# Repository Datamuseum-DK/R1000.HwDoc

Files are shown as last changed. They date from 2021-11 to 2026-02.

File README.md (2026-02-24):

This repository has moved
=========================

The future happens at: https://codeberg.org/Datamuseum-dk/R1000.DigitizingTheSchematics

Rational R1000/400 Machine Readable Hardware documentation
==========================================================

This repository contains the process and the result for
Datamuseum.dk's production of machine readable hardware
documentation for the Rational R1000/400 computer.

The desired output of this project was a machine readable net-list
based on the paper schematics, but because we think the process we
followed to get there may be of general interest, in the context
of computer hardware preservation, this repository captures
the process from A to Z.

But first a bit of…

HOWTO information
-----------------

To refresh/create KiCad symbol files:

	make RebuildSymbols

To add background images to schematics before editing (optional):

	make AddImages

To remove background images *AND* prepare .kicad_sch files for
commit after editing:

	make RemoveImages

If you want to play with the Image-processing:

	make ImageProc

Please note that a lot of disk-space is required for that, and
you may want to put that elsewhere with two symlinks:

	ln -s /tank/downloaded_stuff CacheDir
	ln -s /tank/working_directory WorkDir

Ok, and now to the explanation:

Why ?!
------

In Datamuseum.dk we have a
[running Rational R1000 Computer](https://datamuseum.dk/wiki/Rational/R1000s400)
and since that is in all likelyhood the only one in the world which
will ever run again, we want to implement a software emulation
to preserve this unique machine for posterity.

Normally one would simulate the instruction set of the computer, but
the R1000 has no instruction set, in the sense that the 16 bit codes
the Ada compiler's code generator produces is a private contract with
the Microcode which interprets them.

We have figured out quite a lot about these codes, for instance that
0x008c means:

	Action Heap_Access,Diana_Put_Node_On_Seq_Type 

So, yeah, that's not feasible to emulate.

Instead we aim to emulate at the microcode level, we have almost
complete hardware and some amount of microcode documentation, but
since even the microcode has subroutine calls, that is also a
tall order.

So our first stage is simulating the computer at the circuit
level, all the chips and all the connections between them, and
for that we need the schematics in a form which can be used
to build that simulation, a so-called "net-list".

This project is about producing that from bad-ish photocopies
of the original schematics.

The raw material
----------------

The raw material is 407 schematics on US-letter-sized photo-copies
in a 3-hole binder which we received with the computer, probably
copies of copies of copies of the original 23x14" VersaTec plots.

Here is a random snapshot from the TYPE board:

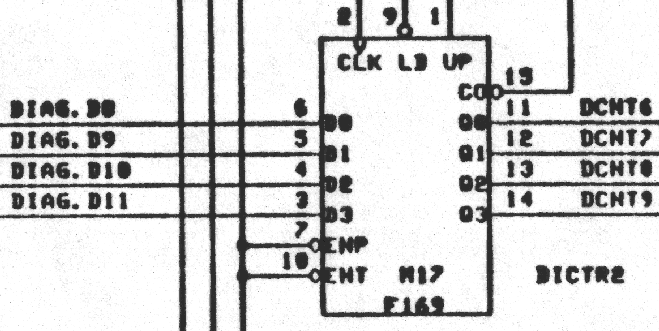
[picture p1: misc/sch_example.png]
Example schematic snippet


The linework is generally OK, but the glyphs have suffered greatly
through the copying, and there are a number of sets which as a rule
cannot be told apart graphically:  B+D, 0+8, E+F, H+M+N etc.

We have scanned the paper in 600DPI 8-bit gray and stored the
resulting images in loss-less PDFs in our
[BitStore](https://datamuseum.dk/wiki/Bits:Keyword/RATIONAL_1000/DOCS)
along with the rest of the documentation for the machine.

Machine reading schematics
--------------------------

The base plan was always to redraw the schematics by hand in KiCad,
but in the absense of prior art about machine reading schematics,
we decided to make an attempt at it, since even moderate succeess
looked like it could translate to substantial savings in time.

We got much better results than we even thought possible, where
more than 90% of all symbols on the schematic could be correctly
identified and placed.

This result comes from a universe of one, and undoubtedly overoptimized
to the these specific schematics, and deriving a lot of benefit from
the restrictions of the machine tools ("Daisy") used in their preparation.

In the end, we did not use the component-list output of the image
processing, we only used geometrically corrected projected images
as background images, since adding components and lines were as fast
of not faster as scrutinizing the machine-placed ones, and dwarfted
by the effort to enter all the textual information, where we never
managed to get a usable read-rate.

However, the code for component identification is included in this
repository, both for future reference, and because the rectangular
chips located add control-points to the geometric correction.

Geometric correction
--------------------

Being able to use the scanned schematics as background images in
KiCad is only realistic, if the skew and other distortions can
be reduced to a neglible level.

The drawing border very conveniently contains arrows for each
inch on the original plot size btween two rectangular frames.

These features, and others, can be machine recognized and used
to build four delaunay-triangulations:

	 from pixel(x, y) to inch(x)
	 from pixel(x, y) to inch(y)
	 from inch(x,y) to pixel(x)
	 from inch(x,y) to pixel(y)

Compared to traditional unskewing by rotation and similar
methods, a delaunay-triangulation permits adding as many
control-points as desired, making it possible to correct
not only skew, but also the uneven feed rates of the copying
machines used along the way:

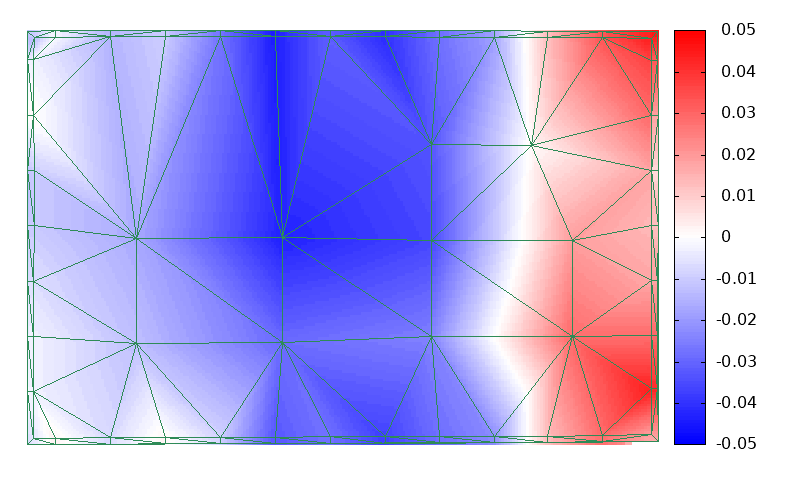
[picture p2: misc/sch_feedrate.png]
Example of uneven feed rate


This is a very typical pattern, for machines with two feed rollers,
one before and one after the imaging zone.  In this case the total
aberation is 0.1" which is a full grid point on the raw material.

The delaunay projections can be built in both  be built in both directions

Using the inch->pixel delaunay-projections to create a corrected
image is a very slow process, but gives very good results:

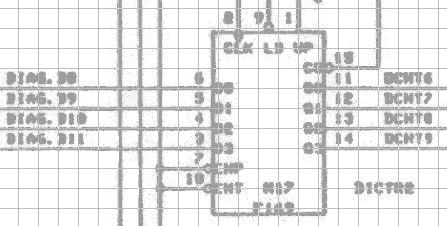
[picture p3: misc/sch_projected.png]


Schematic capture
-----------------

As mentioned above, we ended up doing the schematic capture by hand
using the scanned schematics as background:

Kicad schematic editor with background image

With a symbol library which as closely as possible matches
the original symbols, this is a really fast way to recapture
old schematics.

The most tedious part of the schematic capture was entering all
the text, because it took time to disambiguate 'B' and 'D' end so
on.

In order to catch as many mistakes as possible, we also typed
in the names and types of the chips found on the actual printed
circuit boards, and write scripts to cross-reference information
in the produced netlist with "ground truth".

Symbol library
--------------

Because the original schematics were prepared on Daisy and therefore
restricted to a 0.1" raster, probably in order to drive a VersaTec
electrostatic matrix plotter through a character generator, we were
able to create the KiCad symbols from "ascii-art" like this:

	   +-------+
	   |       |
	 11|       |
	-->+I0     |
	 12|       |
	-->+I1     |
	 13|       |
	-->+I2     |
	 14|       |
	-->+I3     |
	 15|       |10
	-->+I4  PEV+-->
	  1|       |
	-->+I5     |
	  2|       |9
	-->+I6  POD+-->
	  3|       |
	-->+I7     |
	  4|       |
	-->+I8     |
	  5|       |
	-->+I9     |
	  6|       |
	-->+I10    |
	  7|   xnn |
	-->+I11    |
	   |       |
	   | _     |
	   +-------+

These same ascii-arts is what enabled a very high recognition rate of
chips in the machine-reading experiment:  The pins on the four sides
of the chip, can be used to generate a "signature" of the pin locations
which can also be derived from the machine reading process:

	LI_I_I_I_I_I_I_I_I_I_I_IR________I___I__________TB

The non-rectangular components were entered by hand in KiCads component
editor, including the "deMorgan" variations many of them had:

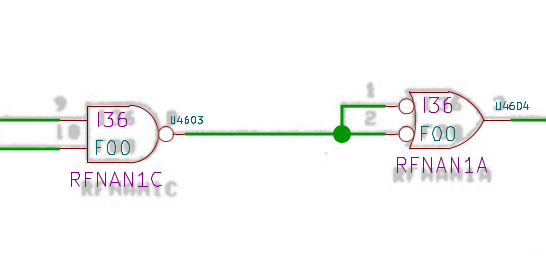
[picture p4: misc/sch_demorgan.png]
NAND gate with demorgan variant


Because the goal is to get a functional netlist for emulation
purposes, we did not bother with multiple units per symbol,
for instance the four NAND gates in a 74F00, we just have
a symbol called "F00" with a single NAND gate.

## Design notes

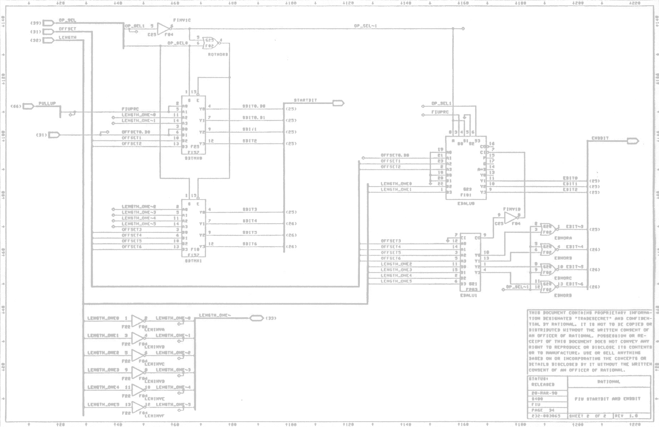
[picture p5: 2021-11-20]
BackgroundImages/FIU/0042/projected_75_light.png

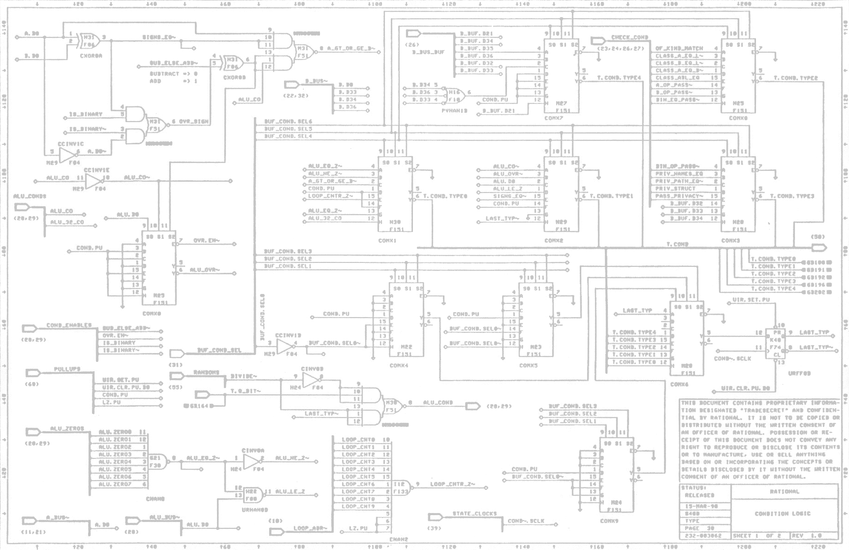
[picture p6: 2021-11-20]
BackgroundImages/TYP/0038/projected_75_light.png

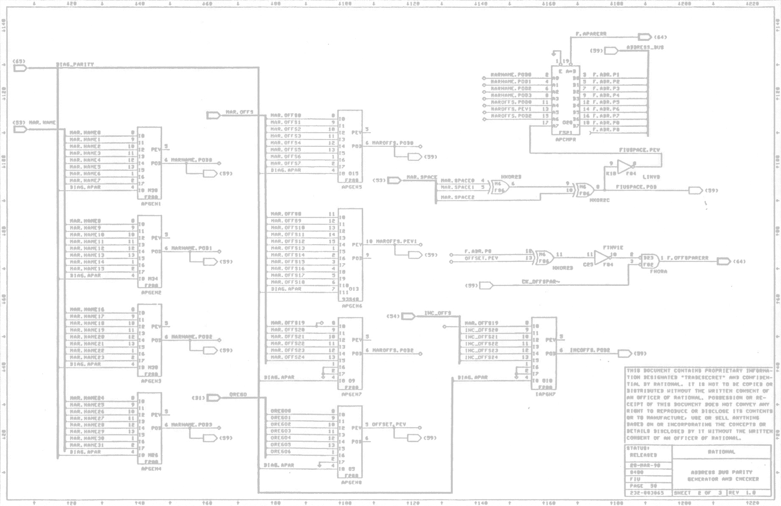
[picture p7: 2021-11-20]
BackgroundImages/FIU/0066/projected_75_light.png

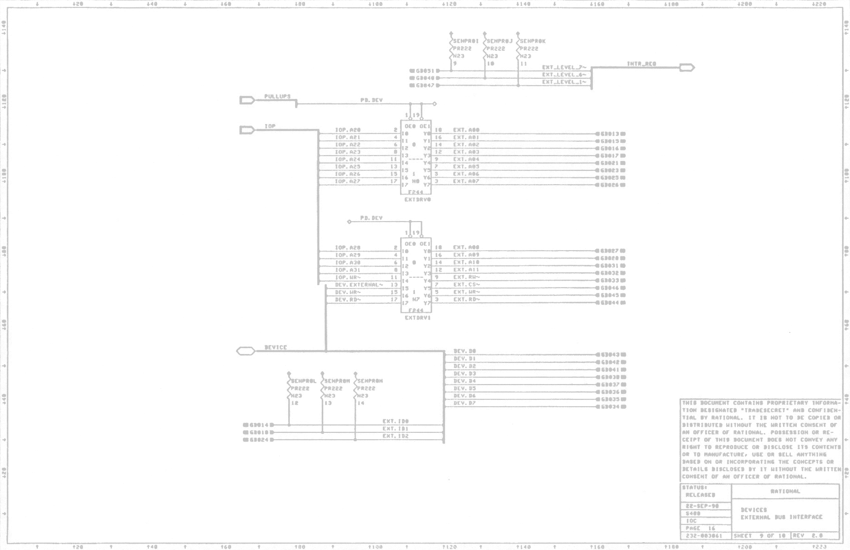
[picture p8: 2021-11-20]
BackgroundImages/IOC/0025/projected_75_light.png

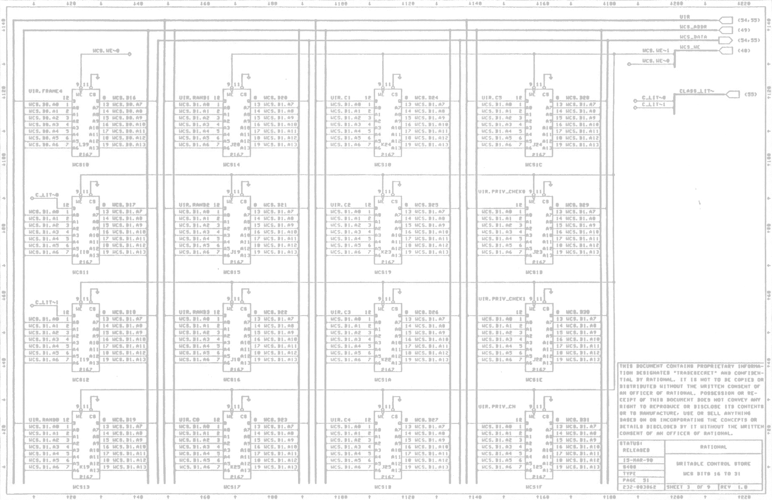
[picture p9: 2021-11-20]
BackgroundImages/TYP/0059/projected_75_light.png

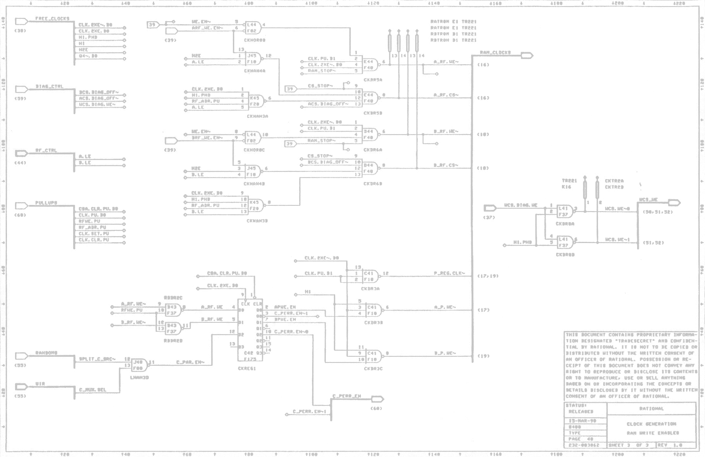
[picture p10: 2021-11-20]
BackgroundImages/TYP/0048/projected_75_light.png

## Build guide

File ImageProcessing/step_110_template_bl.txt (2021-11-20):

--------------------###############--------------------------------------------------##########--------                           -
--------------------###############--------------------------------------------------##########--------                           -
--------------------###############--------------------------------------------------##########--------                           -
--------------------###############--------------------------------------------------###########-------                           -
--------------------###############---------------------------------------------------##########-------                           -
--------------------###############---------------------------------------------------##########-------                           -
--------------------###############---------------------------------------------------##########-------                           -
--------------------###############---------------------------------------------------##########-------                           -
--------------------###############---------------------------------------------------##########-------                           -
--------------------###############---------------------------------------------------##########-------                           -
--------------------###############---------------------------------------------------##########-------                           -
--------------------###############---------------------------------------------------##########-------                           -
---------------------##############---------------------------------------------------#########--------                           -
---------------------##############---------------------------------------------------#########--------                           -
---------------------##############---------------------------------------------------#########--------                           -
---------------------##############---------------------------------------------------#########--------                           -
---------------------##############---------------------------------------------------#########--------                           -
---------------------##############---------------------------------------------------#########--------                           -
---------------------#############----------------------------------------------------#########--------                           -
---------------------##############---------------------------------------------------#########--------                           -
---------------------##############---------------------------------------------------#########--------                           -
---------------------##############--------------------------------------------------###########-------                           -
---------------------##############--------------------------------------------------###########-------                           -
---------------------##############--------------------------------------------------###########-------                           -
--------------------###############---------------------------------------------------##########-------                           -
--------------------###############---------------------------------------------------##########-------                           -
--------------------###############---------------------------------------------------##########-------                           -
--------------------###############---------------------------------------------------##########-------                           -
--------------------###############----------------------------------------------------#########-----------------------------------
--------------------###############---------------------------------------------------#########------------------------------------
--------------------###############---------------------------------------------------#########------------------------------------
--------------------###############----------------------------------------------------########------------------------------------
---------------------##############----------------------------------------------------#########-----------------------------------
---------------------##############----------------------------------------------------#########-----------------------------------
---------------------##############----------------------------------------------------#########-----------------------------------
---------------------##############----------------------------------------------------#########-----------------------------------
---------------------##############----------------------------------------------------##########----------------------------------
---------------------##############----------------------------------------------------#############--#----######------####------##
---------------------##############-----------------------------------------------------###########################################
--------------------###############-----------------------------------------------------###########################################
--------------------###############-----------------------------------------------------###########################################
--------------------###############-----------------------------------------------------###########################################
--------------------###############------------------------------------------------------##########################################
--------------------###############-------------------------------------------------------#########################################
--------------------###############--------------------------------------------------------#####--##----------###----------------##
--------------------###############------------------------------------------------------------------------------------------------
---------------------##############------------------------------------------------------------------------------------------------
---------------------##############------------------------------------------------------------------------------------------------
--------------------###############------------------------------------------------------------------------------------------------
--------------------################-----------------------------------------------------------------------------------------------
--------------------################-----------------------------------------------------------------------------------------------
--------------------################-----------------------------------------------------------------------------------------------
--------------------################-----------------------------------------------------------------------------------------------
--------------------################-----------------------------------------------------------------------------------------------
---------------------##############------------------------------------------------------------------------------------------------
---------------------##############------------------------------------------------------------------------------------------------
---------------------###############-----------------------------------------------------------------------------------------------
---------------------##############------------------------------------------------------------------------------------------------
---------------------##############------------------------------------------------------------------------------------------------
---------------------##############------------------------------------------------------------------------------------------------
---------------------##############------------------------------------------------------------------------------------------------
---------------------##############------------------------------------------------------------------------------------------------
---------------------##############------------------------------------------------------------------------------------------------
---------------------##############------------------------------------------------------------------------------------------------
----------------------#############------------------------------------------------------------------------------------------------
---------------------##############------------------------------------------------------------------------------------------------
---------------------###############-----------------------------------------------------------------------------------------------
---------------------##############------------------------------------------------------------------------------------------------
---------------------##############------------------------------------------------------------------------------------------------
---------------------###############-----------------------------------------------------------------------------------------------
---------------------###############-----------------------------------------------------------------------------------------------
----------------------##############-----------------------------------------------------------------------------------------------
----------------------##############-----------------------------------------------------------------------------------------------
----------------------##############-----------------------------------------------------------------------------------------------
----------------------##############-----------------------------------------------------------------------------------------------
----------------------##############-----------------------------------------------------------------------------------------------
----------------------#############------------------------------------------------------------------------------------------------
---------------------##############------------------------------------------------------------------------------------------------
---------------------##############------------------------------------------------------------------------------------------------
----------------------##############-----------------------------------------------------------------------------------------------
----------------------##############-----------------------------------------------------------------------------------------------
----------------------##############-----------------------------------------------------------------------------------------------
----------------------##############-----------------------------------------------------------------------------------------------
----------------------##############-----------------------------------------------------------------------------------------------
----------------------##############-----------------------------------------------------------------------------------------------
----------------------##############-----------------------------------------------------------------------------------------------
----------------------##############-----------------------------------------------------------------------------------------------
----------------------##############-----------------------------------------------------------------------------------------------
----------------------##############-----------------------------------------------------------------------------------------------
----------------------##############-----------------------------------------------------------------------------------------------
----------------------##############-----------------------------------------------------------------------------------------------
----------------------##############-----------------------------------------------------------------------------------------------
----------------------##############-----------------------------------------------------------------------------------------------
----------------------##############-----------------------------------------------------------------------------------------------
----------------------###############----------------------------------------------------------------------------------------------
----------------------###############----------------------------------------------------------------------------------------------
----------------------#################--------------###-------#--##--#-----#---#--##-----------------------##---------------------
----------------------####################-###-####################################################################################
----------------------#############################################################################################################
----------------------#############################################################################################################
----------------------#############################################################################################################
----------------------#############################################################################################################
----------------------#############################################################################################################
-----------------------############################################################################################################
-----------------------############################################################################################################
-----------------------############################################################################################################
-----------------------############################################################################################################
------------------------###########################################################################################################
-------------------------################-######################################-##################################################
------------------------#--------------------------------##############--------------------------------###-------#-----------------
-----------------------------------------------------------------------------------------------------------------------------------
-----------------------------------------------------------------------------------------------------------------------------------
-----------------------------------------------------------------------------------------------------------------------------------
-----------------------------------------------------------------------------------------------------------------------------------
-----------------------------------------------------------------------------------------------------------------------------------
-----------------------------------------------------------------------------------------------------------------------------------
-----------------------------------------------------------------------------------------------------------------------------------
-----------------------------------------------------------------------------------------------------------------------------------
-----------------------------------------------------------------------------------------------------------------------------------
-----------------------------------------------------------------------------------------------------------------------------------
-----------------------------------------------------------------------------------------------------------------------------------
-----------------------------------------------------------------------------------------------------------------------------------
-----------------------------------------------------------------------------------------------------------------------------------
-----------------------------------------------------------------------------------------------------------------------------------
-----------------------------------------------------------------------------------------------------------------------------------
-----------------------------------------------------------------------------------------------------------------------------------
-----------------------------------------------------------------------------------------------------------------------------------
-----------------------------------------------------------------------------------------------------------------------------------

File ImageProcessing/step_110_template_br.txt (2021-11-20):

-------------------###########----------------##########-----------------
--------------------##########----------------##########-----------------
--------------------##########----------------##########-----------------
--------------------##########----------------##########-----------------
--------------------##########----------------##########-----------------
--------------------##########----------------##########-----------------
--------------------##########----------------##########-----------------
--------------------##########----------------##########-----------------
--------------------##########-----------------#########-----------------
---------------------#########-----------------#########-----------------
---------------------#########-----------------########------------------
--------------------##########-----------------#########-----------------
--------------------##########-----------------#########-----------------
-------------------###########-----------------#########-----------------
-#----------###--#############-----------------#########-----------------
####-#########################-----------------#########-----------------
##############################-----------------#########-----------------
##############################-----------------#########-----------------
##############################-----------------#########-----------------
##############################-----------------#########-----------------
##############################-----------------#########-----------------
------------------############-----------------#########-----------------
--------------------##########-----------------#########-----------------
---------------------#########-----------------#########-----------------
---------------------#########-----------------##########----------------
---------------------#########-----------------##########----------------
---------------------#########-----------------#########-----------------
---------------------#########-----------------#########-----------------
---------------------#########-----------------#########-----------------
---------------------#########-----------------#########-----------------
---------------------#########-----------------#########-----------------
---------------------#########-----------------#########-----------------
---------------------#########-----------------#########-----------------
---------------------#########-----------------#########-----------------
---------------------#########-----------------#########-----------------
---------------------#########-----------------#########-----------------
---------------------#########-----------------#########-----------------
---------------------#########-----------------#########-----------------
---------------------#########-----------------#########-----------------
--------------------##########-----------------#########-----------------
---------------------#########-----------------#########-----------------
---------------------#########-----------------##########----------------
---------------------#########-----------------#########-----------------
---------------------#########-----------------#########-----------------
---------------------##########----------------#########-----------------
---------------------##########----------------#########-----------------
---------------------##########----------------#########-----------------
---------------------##########----------------#########-----------------
---------------------#########-----------------#########-----------------
---------------------#########-----------------#########-----------------
---------------------#########-----------------##########----------------
---------------------#########-----------------#########-----------------
---------------------#########------------------########-----------------
---------------------#########------------------########-----------------
---------------------#########------------------########-----------------
---------------------#########------------------########-----------------
---------------------#########-----------------#########-----------------
----------------------########-----------------##########----------------
---------------------#########-----------------##########----------------
---------------------#########-----------------##########----------------
---------------------#########-----------------##########----------------
---------------------#########-----------------##########----------------
---------------------#########-----------------##########----------------
----------------------########-----------------##########----------------
----------------------########-----------------##########----------------
---------------------#########-----------------##########----------------
---------------------#########------------------#########----------------
--------------------##########------------------########-----------------
-----#--------################------------------########-----------------
#############################-------------------#########----------------
#############################-------------------########-----------------
#############################-------------------########-----------------
#############################------------------#########-----------------
############################--------------------########-----------------
#######---------------#####---------------------########-----------------
------------------------##----------------------########-----------------
------------------------------------------------########-----------------
------------------------------------------------########-----------------
-----------------------------------------------##########----------------
-----------------------------------------------##########----------------
-----------------------------------------------#########-----------------
------------------------------------------------########-----------------
------------------------------------------------########-----------------
-----------------------------------------------#########-----------------
------------------------------------------------########-----------------
------------------------------------------------########-----------------
------------------------------------------------########-----------------
------------------------------------------------########-----------------
------------------------------------------------########-----------------
------------------------------------------------########-----------------
------------------------------------------------########-----------------
------------------------------------------------########-----------------
------------------------------------------------########-----------------
-----------------------------------------------#########-----------------
------#---------------------------------------##########-----------------
#############################---####-----################----------------
#########################################################----------------
########################################################-----------------
#######################################################------------------
######################################################-------------------
##############################################---------------------------
----------------------#######--------###---------------------------------
-------------------------------------------------------------------------
-------------------------------------------------------------------------
-------------------------------------------------------------------------
-------------------------------------------------------------------------
-------------------------------------------------------------------------
-------------------------------------------------------------------------
-------------------------------------------------------------------------
-------------------------------------------------------------------------
-------------------------------------------------------------------------
-------------------------------------------------------------------------
-------------------------------------------------------------------------
-------------------------------------------------------------------------
-------------------------------------------------------------------------

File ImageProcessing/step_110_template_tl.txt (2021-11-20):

------------------------------------------------------------------------------------------------------------------------
------------------------------------------------------------------------------------------------------------------------
------------------------------------------------------------------------------------------------------------------------
------------------------------------------------------------------------------------------------------------------------
------------------------------------------------------------------------------------------------------------------------
------------------------------------------------------------------------------------------------------------------------
------------------------------------------------------------------------------------------------------------------------
------------------------------------------------------------------------------------------------------------------------
------------------------------------------------------------------------------------------------------------------------
------------------------------------------------------------------------------------------------------------------------
------------------------------------------------------------------------------------------------------------------------
------------------------------------------------------------------------------------------------------------------------
------------------------------------------------------------------------------------------------------------------------
------------------------------------------------------------------------------------------------------------------------
------------------------------------------------------------------------------------------------------------------------
------------------------------------------------------------------------------------------------------------------------
------------------------------------------------------------------------------------------------------------------------
------------------------------------------------------------------------------------------------------------------------
------------------------------------------------------------------------------------------------------------------------
------------------------########----------------------------------------------------------------------------------------
-----------------------######################-####------------##########-####---------#---#########------------------###
-----------------------#########################################################################################-#######
-----------------------#################################################################################################
----------------------##################################################################################################
----------------------##################################################################################################
----------------------##################################################################################################
----------------------##################################################################################################
----------------------##################################################################################################
----------------------##################################################################################################
----------------------##################################################################################################
----------------------##################################################################################################
----------------------##################################################################################################
---------------------###################################################################################################
----------------------##################################################################################################
----------------------###################################------------##--###################-----##########---########--
----------------------################--------------------------------------#####------------------------------------#--
-----------------------##############------------------------------------------#----------------------------------------
-----------------------##############-----------------------------------------------------------------------------------
-----------------------##############-----------------------------------------------------------------------------------
-----------------------##############-----------------------------------------------------------------------------------
----------------------###############-----------------------------------------------------------------------------------
----------------------###############-----------------------------------------------------------------------------------
-----------------------#############------------------------------------------------------------------------------------
-----------------------##############-----------------------------------------------------------------------------------
-----------------------##############-----------------------------------------------------------------------------------
-----------------------##############-----------------------------------------------------------------------------------
-----------------------#############------------------------------------------------------------------------------------
-----------------------#############------------------------------------------------------------------------------------
-----------------------##############-----------------------------------------------------------------------------------
----------------------##############------------------------------------------------------------------------------------
----------------------###############-----------------------------------------------------------------------------------
----------------------###############-----------------------------------------------------------------------------------
----------------------###############-----------------------------------------------------------------------------------
----------------------##############------------------------------------------------------------------------------------
----------------------##############------------------------------------------------------------------------------------
----------------------##############------------------------------------------------------------------------------------
----------------------##############------------------------------------------------------------------------------------
----------------------##############------------------------------------------------------------------------------------
-----------------------#############------------------------------------------------------------------------------------
----------------------###############-----------------------------------------------------------------------------------
----------------------##############------------------------------------------------------------------------------------
----------------------##############------------------------------------------------------------------------------------
----------------------##############------------------------------------------------------------------------------------
-----------------------#############------------------------------------------------------------------------------------
-----------------------##############-----------------------------------------------------------------------------------
-----------------------##############-----------------------------------------------------------------------------------
-----------------------##############-----------------------------------------------------------------------------------
-----------------------##############-----------------------------------------------------------------------------------
-----------------------##############-----------------------------------------------------------------------------------
-----------------------##############-----------------------------------------------------------------------------------
-----------------------##############-----------------------------------------------------------------------------------
----------------------###############-----------------------------------------------------------------------------------
----------------------##############------------------------------------------------------------------------------------
-----------------------#############------------------------------------------------------------------------------------
-----------------------#############------------------------------------------------------------------------------------
-----------------------#############------------------------------------------------------------------------------------
-----------------------##############-----------------------------------------------------------------------------------
----------------------##############------------------------------------------------------------------------------------
----------------------##############------------------------------------------------------------------------------------
-----------------------##############-----------------------------------------------------------------------------------
-----------------------#############------------------------------------------------------------------------------------
----------------------##############------------------------------------------------------------------------------------
----------------------###############-----------------------------------------------------------------------------------
-----------------------##############-----------------------------------------------------------------------------------
-----------------------##############-----------------------------------------------------------------------------------
-----------------------##############----------------------------------------------------########---#######-------------
-----------------------##############---------------------------------------------------################################
-----------------------##############---------------------------------------------------################################
-----------------------##############---------------------------------------------------################################
-----------------------##############---------------------------------------------------################################
-----------------------##############---------------------------------------------------################################
-----------------------##############--------------------------------------------------#################################
-----------------------##############--------------------------------------------------#################################
-----------------------##############--------------------------------------------------##################---------------
-----------------------##############--------------------------------------------------############---------------------
-----------------------##############--------------------------------------------------##########-----------------------
----------------------###############--------------------------------------------------##########-----------------------
-----------------------##############--------------------------------------------------##########-----------------------
-----------------------##############--------------------------------------------------#########------------------------
-----------------------###############-------------------------------------------------#########------------------------
-----------------------##############--------------------------------------------------#########------------------------
-----------------------##############--------------------------------------------------#########------------------------
-----------------------##############--------------------------------------------------#########------------------------
-----------------------##############--------------------------------------------------#########------------------------
-----------------------##############--------------------------------------------------#########------------------------
-----------------------##############-------------------------------------------------##########------------------------
-----------------------##############-------------------------------------------------##########------------------------
-----------------------##############-------------------------------------------------#########-------------------------
-----------------------##############-------------------------------------------------#########-------------------------
-----------------------##############-------------------------------------------------#########-------------------------
-----------------------##############--------------------------------------------------########-------------------------
-----------------------##############-------------------------------------------------##########------------------------
-----------------------##############-------------------------------------------------#########-------------------------
-----------------------##############-------------------------------------------------##########------------------------

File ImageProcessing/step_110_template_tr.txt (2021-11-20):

-----------------------------------------------------------------------------------------------------------------------------------------------------------------------------------------------------------------------------------------------------------
-----------------------------------------------------------------------------------------------------------------------------------------------------------------------------------------------------------------------------------------------------------
-----------------------------------------------------------------------------------------------------------------------------------------------------------------------------------------------------------------------------------------------------------
-----------------------------------------------------------------------------------------------------------------------------------------------------------------------------------------------------------------------------------------------------------
-----------------------------------------------------------------------------------------------------------------------------------------------------------------------------------------------------------------------------------------------------------
-----------------------------------------------------------------------------------------------------------------------------------------------------------------------------------------------------------------------------------------------------------
--------------------------------------------------##---------------------------------------------########--------------------------------------------------------------------------------------------------------------------------------------------------
------------------------------------------##-########----------------##########-----------------###########------------------------------------------------------------------------------------------------------------------------------------------------
--------------------#####--------------###############--------------############--------------##############-----------------------------------------------------------------------------------------------------------------------------------------------
-------------------#######-------------#################-----------###############------------###############----------------------------------------------------------------------------------------------------------------------------------------------
-------------------#######------------###################---------#################----------################----------------------------------------------------------------------------------------------------------------------------------------------
------------------########------------###################--------##################---------##################---------------------------------------------------------------------------------------------------------------------------------------------
------------------########------------####################-------###################-------###################---------------------------------------------------------------------------------------------------------------------------------------------
------------------########------------####################------####################------#####################--------------------------------------------------------------------------------------------------------------------------------------------
------------------########------------#####################-----########----########------#####################--------------------------------------------------------------------------------------------------------------------------------------------
------------------########------------#####------##########------######-----########------#####################--------------------------------------------------------------------------------------------------------------------------------------------
------------------########--------------#---------#########--------#--------#########----#######################-------------------------------------------------------------------------------------------------------------------------------------------
-----------------#########------------------------#########-----------------#########----#######################-------------------------------------------------------------------------------------------------------------------------------------------
-----------------##########---------------------###########----------------#########-----#######################-------------------------------------------------------------------------------------------------------------------------------------------
-----------------##########----------------###############----------################-----########################------------------------------------------------------------------------------------------------------------------------------------------
-----------------##########--------------#################---------################------#######################-------------------------------------------------------------------------------------------------------------------------------------------
-----------------###########-----------#################----------################-------#######################-------------------------------------------------------------------------------------------------------------------------------------------
-----------------############----------#################---------################---------######################-------------------------------------------------------------------------------------------------------------------------------------------
-------------##-##############--------#################----------################---------######################-------------------------------------------------------------------------------------------------------------------------------------------
-----------####################------###############------------###########---------------######################-------------------------------------------------------------------------------------------------------------------------------------------
-----------####################------##########-----------------##########----------------######################-------------------------------------------------------------------------------------------------------------------------------------------
-----------#####################----##########------------------########------------------######################-------------------------------------------------------------------------------------------------------------------------------------------
-----------####################-----##########-----------------#########-------------------#####################-------------------------------------------------------------------------------------------------------------------------------------------
-----------####################------#########-----------------#########-------------------####################--------------------------------------------------------------------------------------------------------------------------------------------
------------###################------###############-----------############--#-------------####################--------------------------------------------------------------------------------------------------------------------------------------------
--------------################-------##################--------###################---------###################---------------------------------------------------------------------------------------------------------------------------------------------
---------------##############--------####################------####################---------#################----------------------------------------------------------------------------------------------------------------------------------------------
----------------############---------#####################------###################----------###############-----------------------------------------------------------------------------------------------------------------------------------------------
-----------------##########----------#####################------###################-----------##############-----------------------------------------------------------------------------------------------------------------------------------------------
------------------########------------####################--------#################-------------##########-------------------------------------------------------------------------------------------------------------------------------------------------
---------------------------------------##################----------################---------------######---------------------------------------------------------------------------------------------------------------------------------------------------
-------------------------------------------######---------------------------------------------------##-----------------------------------------------------------------------------------------------------------------------------------------------------
-----------------------------------------------------------------------------------------------------------------------------------------------------------------------------------------------------------------------------------------------------------
-----------------------------------------------------------------------------------------------------------------------------------------------------------------------------------------------------------------------------------------------------------
-----------------------------------------------------------------------------------------------------------------------------------------------------------------------------------------------------------------------------------------------------------
-----------------------------------------------------------------------------------------------------------------------------------------------------------------------------------------------------------------------------------------------------------
---------------------------------------------------------------------------------------------------------------------------------------------------------------------------------------------------------------------------------------###-----------------
-----------------------------------------------------------------------------------------------------------------------------------------------------------------------------------------------------------------------------------#########---------------
-----------------------------------------------------------------------------------------------------------------------------------------------------------------#----------##-----#---------#####--------#############---------#############--------------
-----------------------------------------------------------------------------------------------------------------------------------------####----######-#-#######################-######--####################################################-------------
#--###----------------##-------------------#####-#-----##-##--##---#################-#--##-----###################--#####----#################################################################################################################-------------
################################--#############################################################################################################################################################################################################------------
###############################################################################################################################################################################################################################################------------
###############################################################################################################################################################################################################################################------------
###############################################################################################################################################################################################################################################------------
########################################################################################################################################################################################################################----------#############------------
###################################################################################--##########################################--#########################################-#--#############-----#######----#########----------------###########------------
----#-------#####--############-----#--###########----#####-###########----####---------##--######--######-#--------------------------------------------------------##-----------------------------------------#---------------------##########------------
------------------------------------------------------------------------------------------------#-------------------------------------------------------------------------------------------------------------------------------------#########------------
--------------------------------------------------------------------------------------------------------------------------------------------------------------------------------------------------------------------------------------#########------------
-------------------------------------------------------------------------------------------------------------------------------------------------------------------------------------------------------------------------------------##########------------
-------------------------------------------------------------------------------------------------------------------------------------------------------------------------------------------------------------------------------------##########------------
-------------------------------------------------------------------------------------------------------------------------------------------------------------------------------------------------------------------------------------##########------------
-------------------------------------------------------------------------------------------------------------------------------------------------------------------------------------------------------------------------------------##########------------
-------------------------------------------------------------------------------------------------------------------------------------------------------------------------------------------------------------------------------------##########------------
-------------------------------------------------------------------------------------------------------------------------------------------------------------------------------------------------------------------------------------##########------------
-------------------------------------------------------------------------------------------------------------------------------------------------------------------------------------------------------------------------------------##########------------
-------------------------------------------------------------------------------------------------------------------------------------------------------------------------------------------------------------------------------------##########------------
-------------------------------------------------------------------------------------------------------------------------------------------------------------------------------------------------------------------------------------###########-----------
-------------------------------------------------------------------------------------------------------------------------------------------------------------------------------------------------------------------------------------##########------------
-------------------------------------------------------------------------------------------------------------------------------------------------------------------------------------------------------------------------------------##########------------
-------------------------------------------------------------------------------------------------------------------------------------------------------------------------------------------------------------------------------------##########------------
-------------------------------------------------------------------------------------------------------------------------------------------------------------------------------------------------------------------------------------##########------------
-------------------------------------------------------------------------------------------------------------------------------------------------------------------------------------------------------------------------------------###########-----------
-------------------------------------------------------------------------------------------------------------------------------------------------------------------------------------------------------------------------------------##########------------
-------------------------------------------------------------------------------------------------------------------------------------------------------------------------------------------------------------------------------------##########------------
-------------------------------------------------------------------------------------------------------------------------------------------------------------------------------------------------------------------------------------##########------------
-------------------------------------------------------------------------------------------------------------------------------------------------------------------------------------------------------------------------------------##########------------
-------------------------------------------------------------------------------------------------------------------------------------------------------------------------------------------------------------------------------------###########-----------
--------------------------------------------------------------------------------------------------------------------------------------------------------------------------------------------------------------------------------------#########------------
--------------------------------------------------------------------------------------------------------------------------------------------------------------------------------------------------------------------------------------#########------------
-------------------------------------------------------------------------------------------------------------------------------------------------------------------------------------------------------------------------------------##########------------
-------------------------------------------------------------------------------------------------------------------------------------------------------------------------------------------------------------------------------------##########------------
-------------------------------------------------------------------------------------------------------------------------------------------------------------------------------------------------------------------------------------###########-----------
-------------------------------------------------------------------------------------------------------------------------------------------------------------------------------------------------------------------------------------##########------------
-------------------------------------------------------------------------------------------------------------------------------------------------------------------------------------------------------------------------------------##########------------
-------------------------------------------------------------------------------------------------------------------------------------------------------------------------------------------------------------------------------------##########------------
-------------------------------------------------------------------------------------------------------------------------------------------------------------------------------------------------------------------------------------##########------------
-------------------------------------------------------------------------------------------------------------------------------------------------------------------------------------------------------------------------------------##########------------
-------------------------------------------------------------------------------------------------------------------------------------------------------------------------------------------------------------------------------------###########-----------
-------------------------------------------------------------------------------------------------------------------------------------------------------------------------------------------------------------------------------------###########-----------
-------------------------------------------------------------------------------------------------------------------------------------------------------------------------------------------------------------------------------------###########-----------

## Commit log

2021-11-20 Add the naked schematic files
    [FIU.kicad_sch, IOC.kicad_sch, MEM32.kicad_sch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]
2021-11-20 Bring the RESHA schematics up to level
    [RESHA.kicad_sch, pg_01.kicad_sch, pg_02.kicad_sch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]
2021-11-20 Add the PCB background images
2021-11-21 Visible ECO's on TYP board
2021-11-21 Add the RESHA backplane pins, as an approximation
    [RESHA.kicad_sch, pg_11.kicad_sch]
2021-11-24 Found E31..33 pin 1 (PU)
    [IOC.kicad_sch, pg_18.kicad_sch, pg_20.kicad_sch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]
2021-11-24 Add missing bits, after beeping around on S/N 4995
    [IOC.kicad_sch, pg_20.kicad_sch, pg_32.kicad_sch]
2021-11-27 More typos
    [pg_46.kicad_sch, pg_53.kicad_sch]
2021-11-27 Solve the TCB0~ riddle
    [pg_48.kicad_sch, pg_49.kicad_sch]
2021-11-27 Update index with pg_28
    [IOC.kicad_sch]
2021-11-27 MISC_REG.CLK~ is a local signal
    [pg_64.kicad_sch]
2021-11-27 Fix 2KX8 pinout
    [pg_24.kicad_sch, pg_55.kicad_sch, pg_59.kicad_sch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]
2021-12-24 Forgot git add on this file.
    [pg_28.kicad_sch]
2021-12-30 GB293 -> GB295 for BP.PHASE2X
    [FIU.kicad_sch, pg_62.kicad_sch]
2022-01-02 Fix typos in ROT25 signals.
    (Yes, really, but .kicad_sch is not a very localized fileformat)
    [FIU.kicad_sch, pg_01.kicad_sch, pg_02.kicad_sch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]
2022-01-05 Fix typos
    [pg_10.kicad_sch]
2022-01-05 Fix Typo
    [pg_39.kicad_sch]
2022-01-07 Fix a typo
    [pg_25.kicad_sch]
2022-01-16 Add page titles
    [pg_01.kicad_sch, pg_02.kicad_sch, pg_03.kicad_sch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]
2022-01-16 Add page title index
    [SEQ.kicad_sch]
2022-01-19 Fix a one-char typo on page 55 (and use a newer kicad)
    [TYP.kicad_sch, pg_00.kicad_sch, pg_01.kicad_sch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]
2022-01-21 Align global bus-labels. (Also: New diff'able format)
    [VAL.kicad_sch, pg_00.kicad_sch, pg_01.kicad_sch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]
2022-01-21 New diff'able format
    [TYP.kicad_sch, pg_00.kicad_sch, pg_01.kicad_sch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]
2022-01-22 Add tool to munge KiCad schematics into canonical diff'able form
2022-01-22 Fix LS125 pinout. Further improve diff'ability
    [pg_02.kicad_sch, pg_03.kicad_sch, pg_04.kicad_sch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]
2022-01-22 Fix pin numbers
2022-01-22 Remove extra white-space
    [pg_02.kicad_sch, pg_03.kicad_sch, pg_04.kicad_sch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]
2022-01-22 Fix DISTPAL symbol
    [pg_33.kicad_sch]
2022-01-22 Update TPARPAL and I8051 components for MEM32
    [pg_31.kicad_sch, pg_32.kicad_sch]
2022-01-22 Remove central Q2/Q3 prototyping
    [pg_35.kicad_sch, pg_79.kicad_sch, pg_81.kicad_sch]
2022-01-23 Copy back from KiCad saved version
2022-01-23 Use !PICTURE_PERFECT symbols
    [pg_02.kicad_sch, pg_03.kicad_sch, pg_04.kicad_sch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]
2022-01-23 Remove a debugging workaround
    [pg_62.kicad_sch]
2022-01-26 Fix fall-out from KiCad's search/replace bug
    [pg_16.kicad_sch]
2022-01-26 More C_BUF vs. C cleanup
    [pg_20.kicad_sch, pg_21.kicad_sch]
2022-01-29 Fix typo.
    [pg_54.kicad_sch]
2022-01-30 Add a missing bus-line
    [pg_40.kicad_sch]
2022-01-31 Typo and some notes about clockstops
    [pg_79.kicad_sch]
2022-02-01 Our s400 has PA028-02 in MMPRM3
    [pg_44.kicad_sch]
2022-02-01 Even more C_BUF.D/C.D find/replace fallout
    [pg_15.kicad_sch]
2022-02-02 More C_BUF.D/C.D find/replace fallout
    [pg_10.kicad_sch, pg_17.kicad_sch]
2022-02-02 Minor polish to aid debugging
    [pg_49.kicad_sch]
2022-02-02 Use F37's instead of F00's for clock generation to get 5ns propagation delays.
    [pg_31.kicad_sch]
2022-02-02 Eliminate ERC errors and warnings
    [pg_02.kicad_sch, pg_12.kicad_sch, pg_13.kicad_sch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]
2022-02-03 Update i8051 symbol
    [pg_58.kicad_sch, pg_61.kicad_sch, pg_63.kicad_sch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]
2022-02-04 Typo (probably "Undo-o")
    [pg_29.kicad_sch]
2022-02-06 Add unused pins to PAL symbols
    [pg_31.kicad_sch, pg_33.kicad_sch]
2022-02-11 Avoid cursed coordinate
    KiCad rounds `(mid 5.0442 -3.2889)` to `(mid 5.0441 -3.2889)`
    and vice versa making ERC always claim that the symbol in the
    library has been changed.
2022-02-11 Update to uncursed F20 symbol
    [pg_02.kicad_sch, pg_24.kicad_sch, pg_25.kicad_sch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]
2022-02-12 Fix another 0/8 typo
    [pg_45.kicad_sch]
2022-02-12 Fix copy&paste error
    [pg_23.kicad_sch, pg_24.kicad_sch]
2022-02-18 Include an ECO from s/n 10571/005
    [pg_55.kicad_sch, pg_79.kicad_sch, pg_80.kicad_sch]
2022-02-26 Yet another 0/8 typo
    [pg_29.kicad_sch]
2022-03-02 Connect signals properly
    [pg_36.kicad_sch]
2022-03-05 Fix copy & Paste mistakes
    [pg_14.kicad_sch, pg_18.kicad_sch, pg_19.kicad_sch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]
2022-03-05 F00 -> F37 to delay signals to F652's
    [pg_27.kicad_sch]
2022-03-07 Add missing labels
    [pg_55.kicad_sch, pg_60.kicad_sch]
2022-03-10 More 0/8 typos
    [pg_45.kicad_sch]
2022-03-10 Yet a 0/8 misreading
    [pg_84.kicad_sch]
2022-03-11 Missing bus
    [pg_49.kicad_sch]
2022-03-11 Improve kicad symbol generation machinery
2022-03-12 Collapse the two mirror variants of F245
    [pg_03.kicad_sch, pg_11.kicad_sch, pg_14.kicad_sch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]
2022-03-12 Add _ for inverting pin names
2022-03-14 Add missing bus
    [pg_55.kicad_sch]
2022-03-18 Typo: O/0
    [pg_20.kicad_sch]
2022-03-18 Switch to newer sexp
2022-03-19 Avoid duplicate pin-names
    [pg_05.kicad_sch, pg_10.kicad_sch, pg_11.kicad_sch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]
2022-03-28 Properly sort NAND pin names
    [pg_03.kicad_sch, pg_05.kicad_sch, pg_08.kicad_sch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]
2022-03-29 Update 2167 Q output to 3-state
    [pg_36.kicad_sch, pg_37.kicad_sch, pg_38.kicad_sch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]
2022-04-04 Fix typos in symbol pin-names
    [pg_03.kicad_sch, pg_10.kicad_sch, pg_16.kicad_sch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]
2022-04-08 Add delay for STACK_SIZE_ZERO_FRU.SEQ
    [pg_60.kicad_sch]
2022-04-13 F181's A=B output is open collector
    [pg_12.kicad_sch, pg_20.kicad_sch, pg_21.kicad_sch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]
2022-05-01 New KiCad
    [FIU.kicad_sch, IOC.kicad_sch, MEM32.kicad_sch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]
2022-05-04 Add (unused) pin 17 on TPARPAL
    [MEM32.kicad_sch, pg_31.kicad_sch]
2022-05-26 New Kicad version
    [SEQ.kicad_sch, pg_01.kicad_sch, pg_02.kicad_sch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]
2022-05-29 Fix Yet Another 0/8 misreading. SEQ now passes all tests
    [SEQ.kicad_sch, pg_20.kicad_sch]
2022-06-02 MUXLPAL and MUXEPAL are different. Typos
    [MEM32.kicad_sch, pg_19.kicad_sch, pg_20.kicad_sch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]
2022-06-03 Add propagation delay to some clocksignals
    [pg_30.kicad_sch, pg_31.kicad_sch]
2022-06-04 Use "bidirectional" as intended
    [FIU.kicad_sch, IOC.kicad_sch, MEM32.kicad_sch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]
2022-07-01 Fix NOVRAM reset
    [TYP.kicad_sch, VAL.kicad_sch, pg_58.kicad_sch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]
2022-07-08 Add EMU schematics
    [EMU.kicad_sch]
2022-07-14 Solve a setuptime issue with FIFO counters
    [IOC.kicad_sch, pg_59.kicad_sch, pg_60.kicad_sch]
2022-07-16 Swap latch to register to solve problem in response fifo
    [pg_59.kicad_sch]
2022-08-07 Fix 0/8 typo
    [SEQ.kicad_sch, pg_01.kicad_sch, pg_02.kicad_sch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]
2022-08-07 Align to grid
    [IOC.kicad_sch, pg_01.kicad_sch, pg_02.kicad_sch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]
2022-08-28 Fix the HALT pin
    [pg_02.kicad_sch, pg_07.kicad_sch, pg_25.kicad_sch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]
